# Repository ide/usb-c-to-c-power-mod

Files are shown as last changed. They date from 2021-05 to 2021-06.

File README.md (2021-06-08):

# USB-C-to-C Power Mod Flex PCB

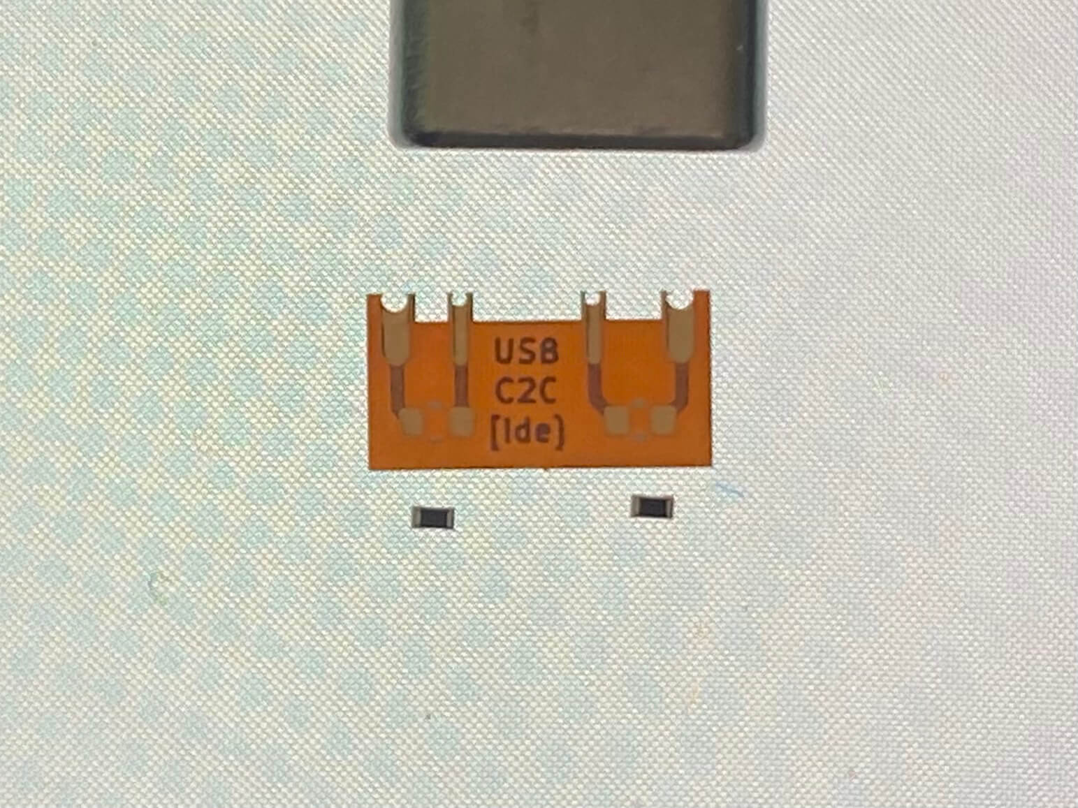
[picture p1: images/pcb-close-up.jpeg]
Flex PCB and SMD resistors with a USB-C cable for scale


Many devices have a USB-C connector to charge or power them. This is very convenient given the popularity of USB-C, its reversible cable design, and sturdy, compact design.

However, some devices will not draw power when using a USB-C-to-C cable connected to a spec-compliant charger, but will when using a USB-A-to-C cable. The USB-C specification requires upstream facing ports (UFPs), the port of the device receiving power, to connect pull-down resistors to the configuration channel (CC) pins. These missing pull-down resistors are a common reason why devices can draw power with A-to-C cables but not C-to-C ones.

Wouldn't it be great to be able to add these resistors and enable USB-C-to-C power? This mod does just that. It is a small flex PCB with pads for two 5.1kohm pull-down resistors between CC1 and CC2, respectively, and GND.

### Circuit
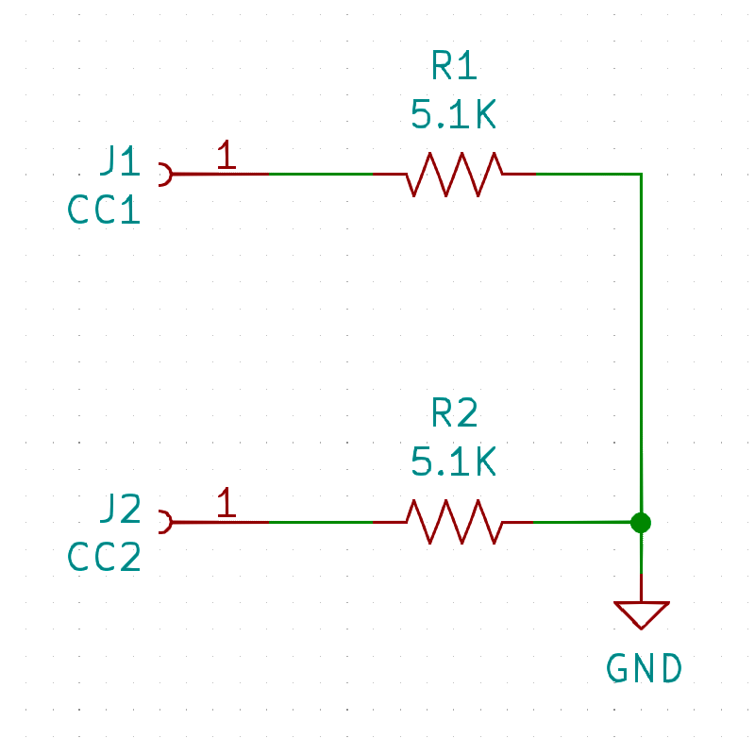
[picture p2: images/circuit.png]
Circuit schematic


### PCB
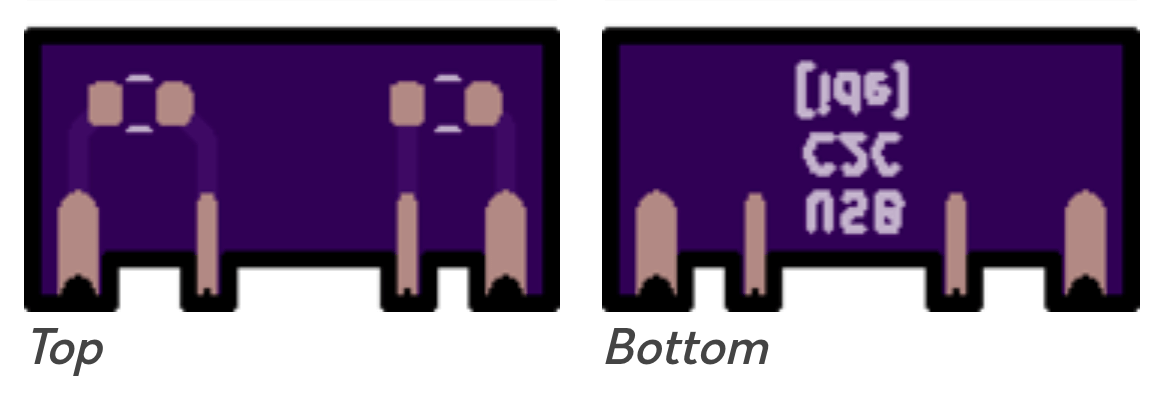
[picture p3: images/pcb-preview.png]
PCB preview


## Supported devices

This PCB can fit into a wide variety of devices whose **USB-C connectors soldered onto 12 pads**. (Note: these connectors are sometimes described as having "16+8 dummy pins". Four of the VBUS pins are wired to two VBUS pads and four of the GND pins are wired to two GND pads, which is why the USB-C port has 16 active pins but is soldered to only 12 pads.) The number of soldered pins varies between USB-C connectors; be sure to inspect the main PCB of your device and ensure the USB-C connector has 12 soldered pins. If your device's USB-C connector has a different number of pins or has through-hole pins, this PCB will not work; however, the concept of connecting two 5.1kohm resistors between the CC pins and ground would work if you were to alter this mod.

Also, the device's PCB needs to have room behind the USB-C connectors to install the mod. The mod is very small but does require a few millimeters of clearance behind the USB-C connector.

## Flex PCBs

Flex PCBs are more expensive than rigid PCBs but are much thinner, making this mod less obtrusive and easier to retrofit into more devices. The PCB also needs to be thin in order to solder its castellations to the CC and GND pads of the main PCB.

## Required equipment and skills

### Parts

* 1x flex PCB
  * [OSH Park](https://oshpark.com/) is a great option worldwide. You can order this PCB from them [here](https://oshpark.com/shared_projects/3YgTXJvQ). Make sure to select the "Flex" option during checkout!
* 2x 5.1kΩ 0402 resistors
  * Order extras as they are difficult to find if lost on the floor
  * Preferably ±10% or better tolerance
  * [Panasonic ERJ-2GEJ512X](https://www.digikey.com/en/products/detail/ERJ-2GEJ512X/P5.1KJCT-ND/147043)

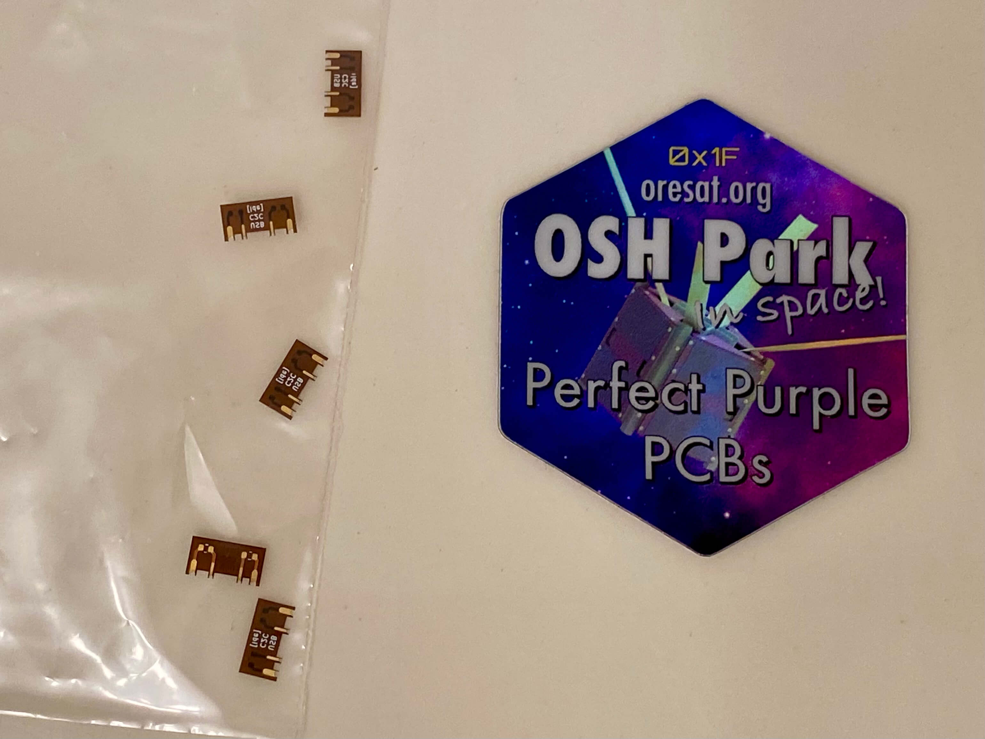
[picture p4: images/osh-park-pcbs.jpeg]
Flex PCBs from OSH Park


### Tools

* A multimeter that can measure continuity, resistance, and voltage
* A fine-tipped soldering iron, solder, flux, and solder braid
* Q-tips and 91-99% isopropyl alcohol or electrical cleaner
* Precision tweezers

### Skills

You will need to solder two SMD resistors to the flex PCB and the flex PCB to your device's main PCB. A steady hand is necessary and soldering experience is highly recommended. USB connectors are subject to stress and making the sub-millimeter solder joints strong will help keep your mod working for a long time.

Knowledge of electronic circuits and how to use a multimeter is also recommended, particularly if you need to debug an issue.

## Installation

The goal is to add one resistor between pad A5 (CC1) and GND and one resistor between pad B5 (CC2) and GND. First use a multimeter to test for continuity and measure resistance between CC1 and GND to ensure the circuit is open. Do the same with CC2 and GND. You may find it helpful to refer to [a diagram](https://gct.co/files/drawings/usb4105.pdf) of the USB-C connector to identify the pads. If the circuit is closed, do not install this mod; the point of this mod is to install missing pull-down resistors.

Lightly tin the pads on the underside of the flex PCB. This will make it easier to establish a good electrical connection with the USB-C connector. Wick away excess solder with your solder braid to prevent it from bridging the connector's pads during installation.

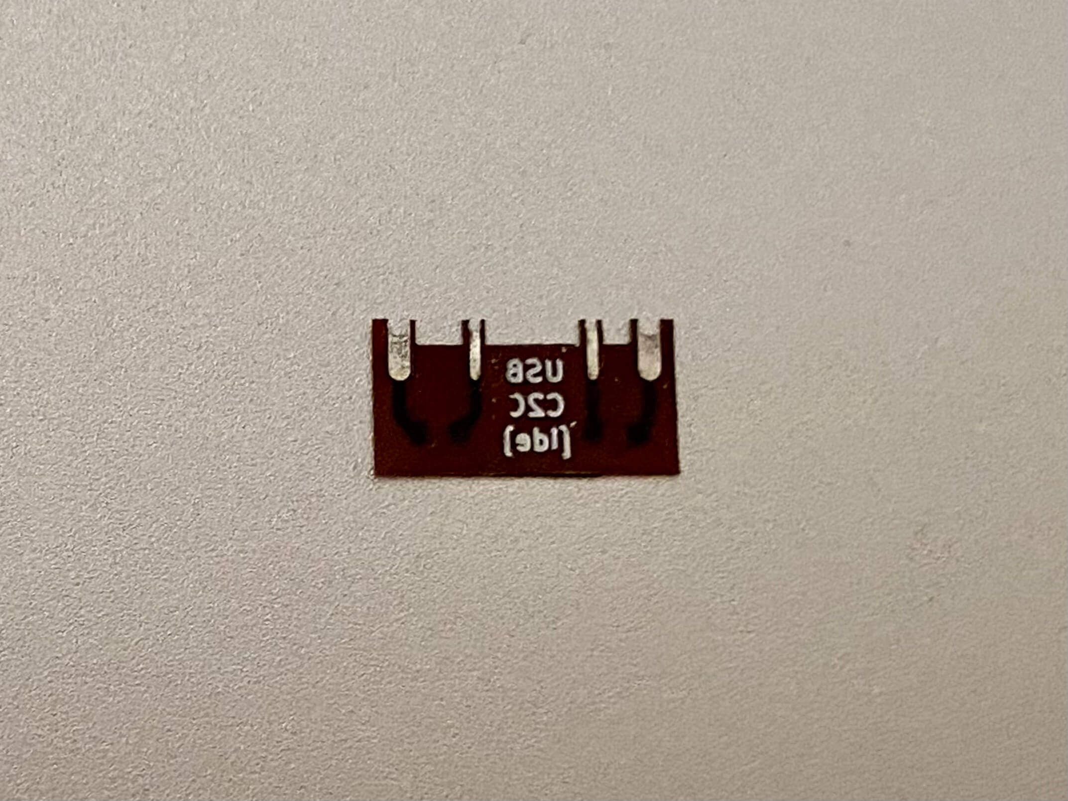
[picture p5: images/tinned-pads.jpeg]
Tinned pads on the PCB's underside


Solder the two SMD resistors to the flex PCB. Use tweezers, patience, and a nicely tinned soldering iron. Measure the resistance between the flex PCB's pads to ensure it reads 5.1kΩ between each CC pad and its neighboring GND pad. Clean away the flux with isopropyl alcohol and Q-tips.

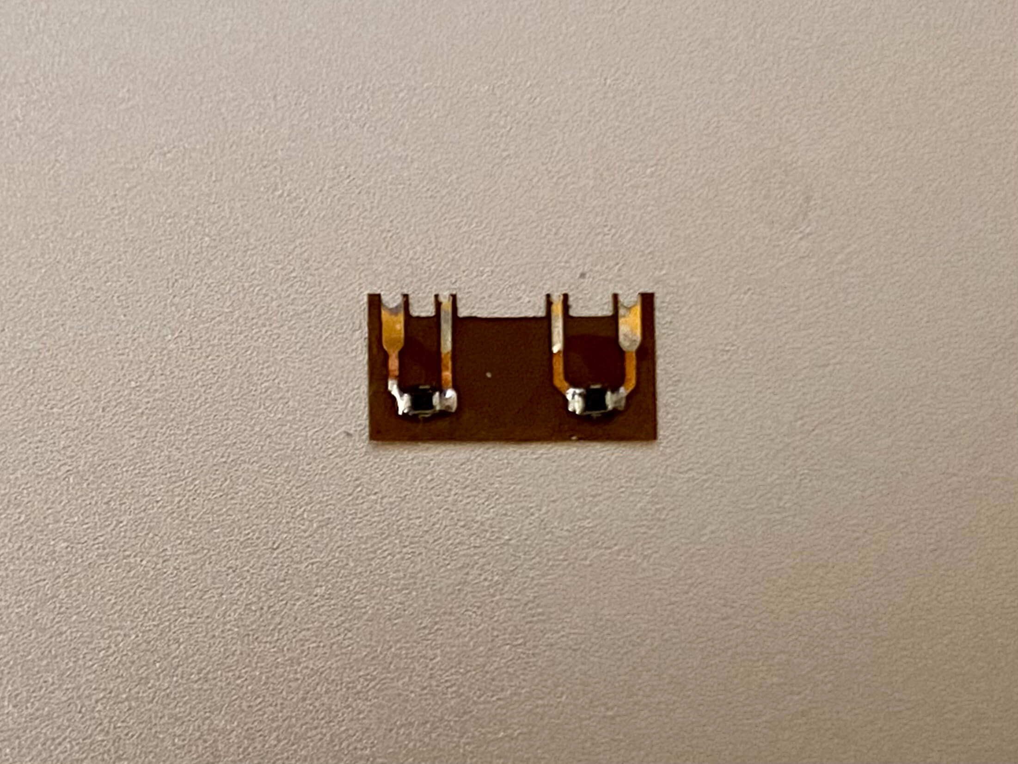
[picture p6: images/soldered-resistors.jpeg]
Pull-down resistors soldered on


Align the flex PCB with the pins along the back of the USB-C connector. The flex PCB's pads should overlap slightly with the USB-C connector's pads and line up with the two GND pads, CC1, and CC2.

Solder the flex PCB to the USB-C connector. Start by soldering one pad down to hold it in place and then solder the rest of the pads. Once the pads are soldered down, it may help to revisit each of them: carefully press down with tweezers, gently reflow each pad for a few seconds, and hold your tweezers in place for a moment after lifting your iron to establish a strong solder joint. The goal is to create a good electrical connection between the flex PCB's pads and the USB-C connector's pads.

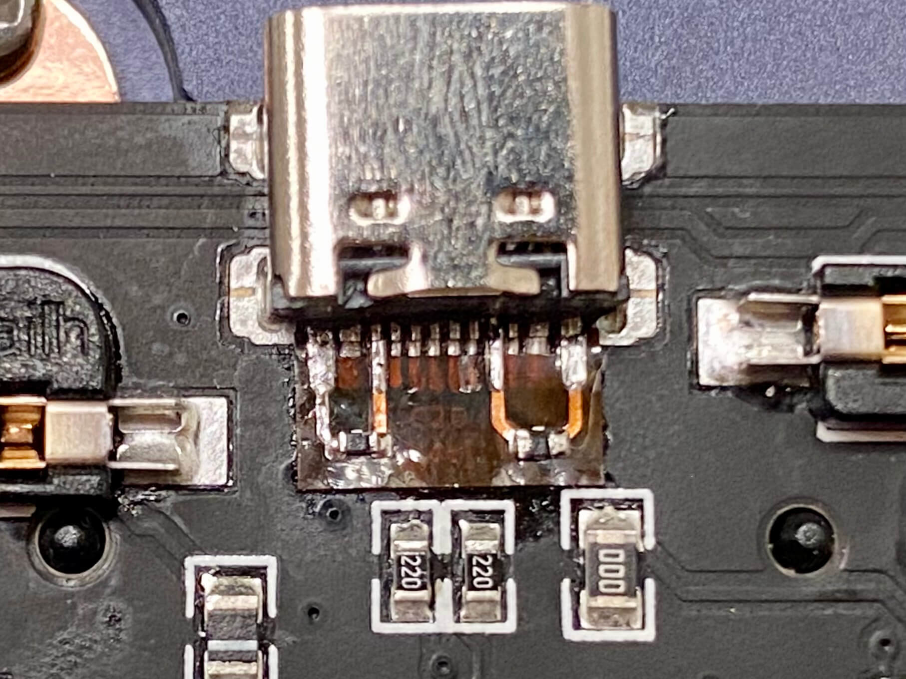
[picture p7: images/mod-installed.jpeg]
Flex PCB mod installed over the USB-C connector


Measure the resistance between the CC pins of the USB-C connector and GND. It should read 5.1kΩ for each pin. As a sanity check, the resistance between the two CC pins should be 10.2kΩ.

Check for short circuits between each of the USB-C connector's neighboring pins. Ensure none of the pins are bridged, including underneath the flex PCB. You must clean up solder bridges before powering your device.

Use isopropyl alcohol to leave your PCB clean before reassembling your device.

Plug in a USB-C-to-C cable. If all has gone well, your device should receive power. There should be a 5V potential between VBUS and GND. (Do not attempt to measure the current across VBUS and GND in parallel with a multimeter or you will likely short circuit and damage your device.)

Gently wiggle the connector to verify the connection is reliable. An unreliable connection may indicate weak solder joints that need to be reflowed. Unplug the USB-C cable and flip it over to check that your device receives power in both orientations. 

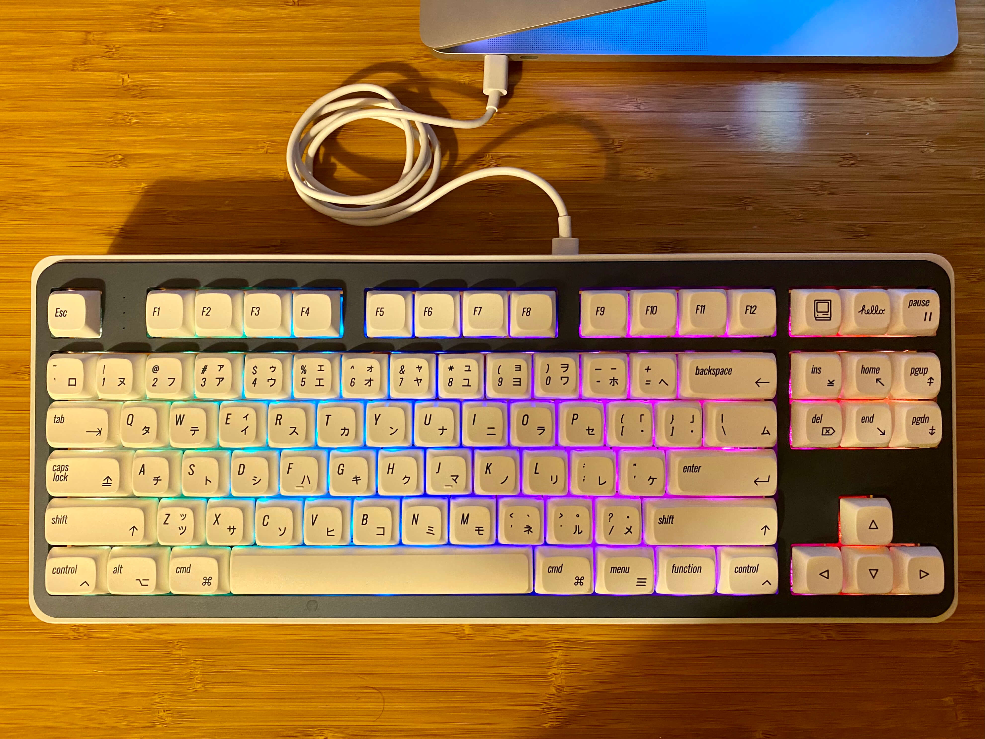
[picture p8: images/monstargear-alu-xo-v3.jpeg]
Keyboard powered with USB-C-to-C cable


## Help and support

You can use this mod however you'd like under the terms of the MIT License.

Speaking plainly, other forums or chats on the internet are better places to look for help than this repo.

You are responsible for any damage to your devices that might come from this mod or trying to install this mod.

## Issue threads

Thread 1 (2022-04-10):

Would it be possible to update the PCB so that A6 and A7 can be shorted to B6 and B7 (for USB 2.0 data purposes)

CSab6482, 2022-04-10:
Hello, I just wanted to say thank you for providing such a useful PCB for modernizing our charging ports.

I like that the 12-pin connector is used here because it also has the necessary connections for Data+ and Data-. While I do not intend to use this port in applications where I want to retain data transfer, I think it would make a useful addition to the project if it were possible.

[Here](https://imgur.com/a/4DTMLal) is a rough pinout I made of the connector. I'm not sure if it's possible to short the USB 2.0 Data pins together without overlapping them, but I do think it would be useful if they could be bridged and then there was a larger pad area to solder to for D+ and D-.

I was inspired to make this feature request by page 7 of [this document](https://www.st.com/content/ccc/resource/technical/document/application_note/group0/93/26/b0/0f/a6/cf/49/bb/DM00294046/files/DM00294046.pdf/jcr:content/translations/e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), which I have screenshotted and attached below.
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
Additionally, [this Stack Exchange answer](https://electronics.stackexchange.com/a/291427) gave a similar solution.

ide, 2022-04-10:
Hi, I'm not planning on changing the features of this PCB but maybe I can offer guidance for how to make the changes. The original intent of this PCB was to "patch" a keyboard that already had a USB-C port but was missing the pulldown resistors needed for C-to-C charging. I left the data pins alone since they were working.

I made the PCB using free software called [KiCad](https://www.kicad.org/). I used an older version (v5.1.10) but I suspect v6 will be able to import the project.

You'll need to add four more pads to the PCB for A6/A7/B6/B7. Copying and pasting one of the existing CC pads is probably easiest since it's already the correct dimensions.

OSH Park's flex PCBs support two copper layers. Each layer is like a floor of a building -- the hallways (traces) on one floor (layer) are independent from hallways of another floor (modulo electromagnetic interference, but don't think that is an issue here). Add a small trace from A6 to B6 on the top layer and a small trace from A7 to B7 on the bottom layer. These traces will be covered by solder mask so they don't short other components on the device.

You also mentioned solder pads for the data pins. Add two test pads to the top layer. Add a trace from one of the pads to the A6/B6 trace. For the A7/B7 trace you'll need to add a via, which is like a stairwell between floors, to create a path from the other test pad to the bottom layer where the A7/B7 trace is.

CSab6482, 2022-04-10:
Awesome, thank you for all of this helpful information. If I do complete this modification, should I make a pull request, or would a fork be more appropriate?

ide, 2022-04-10:
I'd suggest keeping a separate repo since the intent behind the PCBs is different and I set up this repo more to share my work than maintain it.

CSab6482, 2022-04-20:
I've never used KiCad before, and this is what I was able to whip up by just copy and pasting some stuff and relocating it.
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
I have a feeling I'm doing something wrong, and there is a better way. I tried following some tutorials but I've still got a ways to go before I can successfully achieve this. Could you point me to any relevant tutorials? Thank you.

ide, 2022-04-21:
That looks roughly right to me. Sorry I don't have any tutorials. I searched online for specific things I wanted to do and learned the parts of KiCad I needed as I went when I was figuring things out. OSH Park shows a preview of the board once you upload the Gerber files, which should give you an idea of whether the board physically looks right.

Closed 2022-04-10.

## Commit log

2021-05-14 Add new KiCad project files
    This is a newly initialized KiCad project.
    [USB-C-to-C Power Mod.kicad_pcb, USB-C-to-C Power Mod.sch]
2021-05-16 Add schematic, flex PCB footprints, partial PCB design
    [USB-C-to-C Power Mod.kicad_pcb, USB-C-to-C Power Mod.sch]
2021-05-16 First version of board with complete edge cuts
    This is the first complete version of the board with the edge cuts, traces, and pads.
    [USB-C-to-C Power Mod.kicad_pcb]
2021-05-16 Adjust edge cuts to give fingers more clearance + duplicate PCB for OSH Park
    The tolerances of the edge cuts are somewhat large (+/- 5 mil) so nudge the edge cuts up by 5 mil. If needed, it's easy to trim the flex PCB if the fingers are too long.
    Also, the PCB is too small for OSH Park so duplicate it to meet their minimum size.
    [USB-C-to-C Power Mod.kicad_pcb]
2021-05-16 Add generated gerbers + drill file
    This makes it easier to upload to OSH Park or other PCB fabs.
    [USB-C-to-C Power Mod-B_Cu.gbl, USB-C-to-C Power Mod-B_Mask.gbs, USB-C-to-C Power Mod-B_SilkS.gbo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]
2021-05-16 Set board thickness to match flex PCB thickness
    In the 3D render to make the board look thinner, use 0.26416mm instead of 1.6mm.
    [USB-C-to-C Power Mod.kicad_pcb]
2021-05-16 Add image of the circuit schematic to the readme
2021-05-19 [readme] Add link to OSH Park shared project + instructions
    This makes it easier for folks to order the PCB. Also add installation instructions.
2021-06-08 [readme] Add photos to the installation instructions
    Added photos at various installation steps. Also added more instructions on tinning pads and testing that the USB-C cable is reversible (can be flipped upside down) and the solder joints are reliable.
